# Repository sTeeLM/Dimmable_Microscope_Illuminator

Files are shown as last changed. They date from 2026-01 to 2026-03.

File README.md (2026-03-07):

# Dimmable Microscope Illuminator  
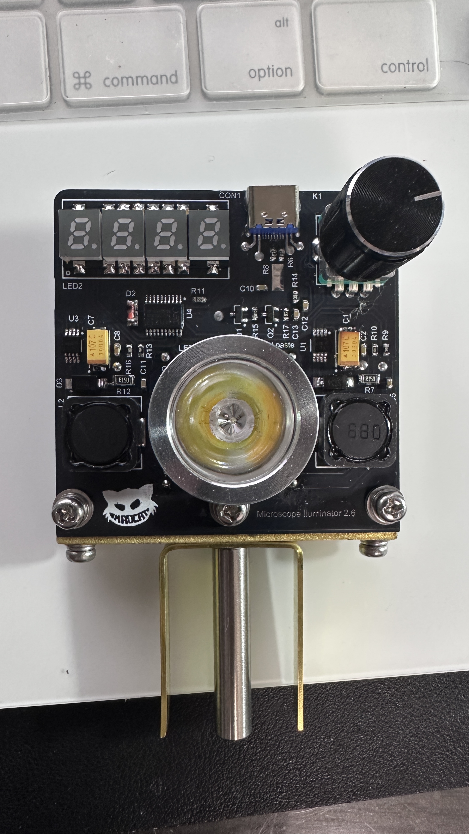
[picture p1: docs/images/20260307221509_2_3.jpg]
图片


### 产品概述：  
本款 LED 补光光源专为精密显微镜观察、工业检测及手工维修设计。产品采用 3W 高功率 LED 芯片，配合 USB 5V 通用供电方案，在保证卓越亮度的同时兼顾了使用的便携性。其灵活的设计使其成为实验室、维修台及科研教育的理想照明方案。  

#### 核心特性：
* 3W 工业级亮度：搭载高能效 LED 模组，光束集中且光照充足，能够清晰捕捉被测物的微小细节。
* USB 5V 安全供电：支持电脑、移动电源或标准手机充电器供电，即插即用，适应多种移动工作场景。
* 无极亮度调节：内置精密调光旋钮，支持 0-100% 亮度线性调节，有效防止光线过强引起的视觉疲劳或成像反光。
* 无极色温调节：支持 0-100% 色温3000K到6000K之间无极调节。
* 低功耗与低发热：LED 冷光源技术确保长时间工作下发热量极低，保护精密样本不受温度影响。

### Product Overview:
This LED illuminator is specifically engineered for precision microscopy, industrial inspection, and manual repair. Featuring a high-power 3W LED chip and a universal USB 5V power solution, it delivers exceptional brightness combined with maximum portability. Its versatile design makes it an ideal lighting solution for laboratories, workstations, and scientific research.  

#### Key Features:
* 3W Industrial Brightness: Equipped with a high-efficiency LED module, it provides a concentrated and powerful beam to reveal the finest details of the specimen.
* USB 5V Safe Powering: Powered via any standard USB port (laptop, power bank, or mobile charger), offering plug-and-play convenience for various mobile working environments.
* Stepless Dimming: Features a built-in precision dimmer knob for 0-100% linear brightness adjustment, preventing eye fatigue and reducing glare on reflective surfaces.
Stepless Color Temperature Adjustment: Supports seamless adjustment from 0% to 100% across a color temperature range of 3000K to 6000K.
* Low Power & Heat: Advanced LED cool-light technology ensures minimal heat emission even during prolonged use, protecting sensitive samples from thermal damage.

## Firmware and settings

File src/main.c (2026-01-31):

#include <STC8G.H>

#include "debug.h"
#include "eerom.h"
#include "gpio.h"
#include "com.h"
#include "tm1650.h"
#include "led.h"
#include "delay.h"
#include "task.h"
#include "clock.h"
#include "button.h"
#include "sm.h"
#include "task.h"

void main(void)
{

  EA = 1; 
  
  debug_initialize();
  gpio_initialize();
  com_initialize();
  
  eerom_initialize();
  tm1650_initialize();
  led_initialize();
  
  clock_initialize();
  button_initialize();
  
  task_initialize();
  sm_initialize();
  
  tm1650_set_dig(0, 0, '1');
  tm1650_set_dig(1, 0, '2');  
  tm1650_set_dig(2, 0, '3');
  tm1650_set_dig(3, 0, '4');   
  while(1) {
    task_run();
  }
}

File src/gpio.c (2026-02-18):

#include "gpio.h"
#include "debug.h"


void gpio_initialize(void)
{
 
  P0M0 = 0x00;
  P0M1 = 0xFF;
  P1M0 = 0x0F;  // SCL, SDA 开漏输出，DMI1，DMI2推挽输出
  P1M1 = 0xFC;
  P2M0 = 0x00;
  P2M1 = 0xFF;
  P3M0 = 0x00;
  P3M1 = 0xFC;  // serial 准双向口
  P4M0 = 0x00;
  P4M1 = 0xFF;
  P5M0 = 0x00;
  P5M1 = 0xFF;
  
  I2C_SDA   = 1;
  I2C_SCL   = 1;
  
  LED_DIM1  = 0;
  LED_DIM2  = 0;  

}

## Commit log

2026-01-26 电路图完成
    [DMI.PcbLib, DMI.PrjPcb, DMI.SchDoc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]
2026-01-28 add PWM simulate
2026-01-28 原理图画完
    [DMI.PcbLib, DMI.SchDoc, DMI.SchLib]
2026-01-30 evaluation board finished
2026-01-30 code framework done
2026-01-30 add led
    [DMI.SchDoc]
2026-01-31 外设全部调通，开始写LED
2026-01-31 正在调试led
2026-01-31 软件部分写完了呢！
2026-02-01 面包板彻底跑通了！
    [DMI.SchDoc]
2026-02-02 PCB V2.1
    [DMI.PcbDoc, DMI.PcbLib, DMI.PrjPcb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]
2026-02-02 PCB V2.2
    [DMI.PcbDoc, DMI.SchDoc]
2026-02-02 PCB V2.3
    增加了一些大电容，解决了灯光闪烁的问题
    [DMI.PcbDoc, DMI.PcbLib, DMI.SchDoc]
2026-02-02 固件：升级
    原来息屏后，再次亮起还是息屏前状态，以及重新上电后也是上次断电状态。
    这样的设计不是很人性，因为调好之后会长时间不动，需要调的时候一般都是调亮度而不是调色温。
2026-02-03 新功能：关机。。。
    1. 在没有改电路的前提下，弄了个伪关机，关机电流1~2mA，这对于常态插着USB的设备还行吧？
    2. 添加了开机、关机画面。。。
2026-02-04 PCB V2.4
    [DMI.PcbDoc]
2026-02-05 bug fix
    [DMI.PcbDoc, DMI.PcbLib]
2026-02-18 PCB 2.5
    [DMI.PcbDoc, DMI.PcbLib, DMI.SchDoc]
2026-02-18 bugfix
    P3.0，3.1的IO口配置不对
2026-02-18 PCB画出bug
    崩溃，A，B两个label，数码管和EC11重名了
    [DMI.PcbDoc, DMI.SchDoc]
2026-03-01 PCB 2.6
    傻逼PCB数码管上下颠倒了。。。
    [DMI.PcbDoc, DMI.PcbLib, DMI.PrjPcb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]
2026-03-07 交换C和CC的顺序，改为旋钮顺时针旋转亮度变大，更符合直觉
2026-03-07 添加图片
